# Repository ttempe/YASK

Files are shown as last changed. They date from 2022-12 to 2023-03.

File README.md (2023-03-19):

YASK - Yet Another Steno Keyboard.
This is a keyboard designed for use with Plover, through the Gemini PR protocol.

To order the PCB, send Gerber_PCB_Steno Keyboard.ZIP to your local PCB shop. Choose the default/cheapest answer to all their questions. 
Here are the build instructions for V1: https://youtu.be/82yD0RMeEw8
V2 instructions are upcoming.

You now have 2 versions to choose from:
* V1: is ortholinear, and uses Cherry-type key switches
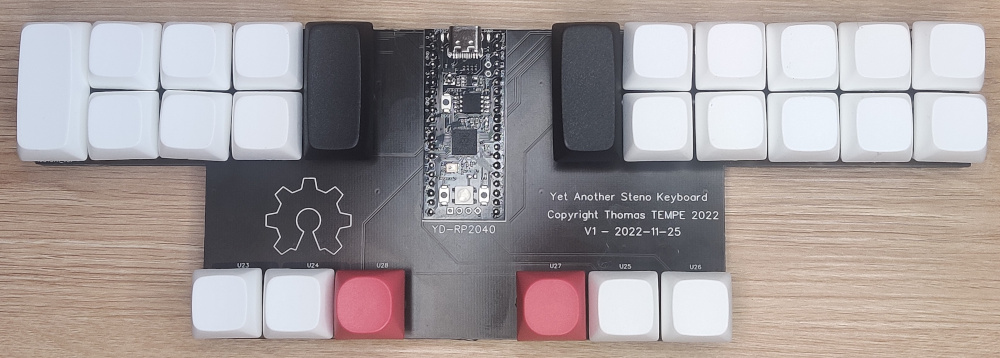
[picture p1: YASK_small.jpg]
Photo of YASK V1


* V2.1: has vertical stargger, is angled (10° each hand), requires Kailh Choc key switches (either with or without hot-swap sockets), and features optional key plates. Moreover the left pinky and the left/right # and * are wired separately, allowing for future evolutions.
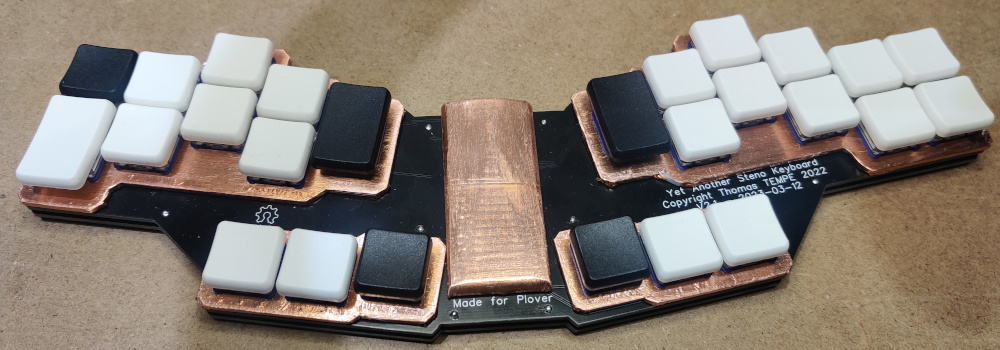
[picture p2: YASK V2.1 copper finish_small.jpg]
Photo of YASK V2 with custom copper finish


Here you can find the design files for the PCB: 
* YASK V1 on OSW Hub: https://oshwhub.com/thomastempe/steno-keyboard
* YASK V2 on OSW Hub: https://pro.lceda.cn/editor#id=24756c8465f9488d9ce5336baf65117a

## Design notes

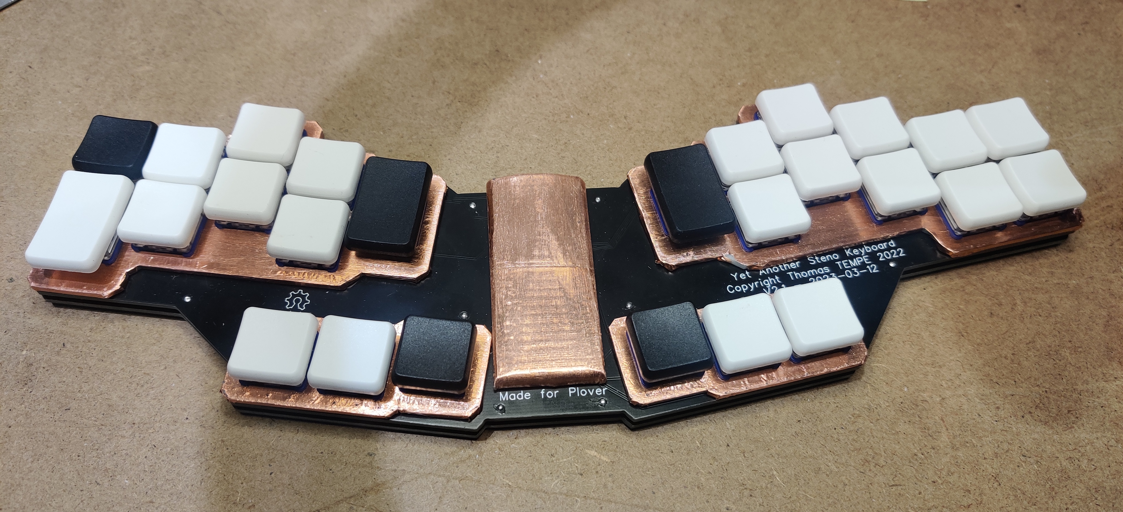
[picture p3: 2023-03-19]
YASK V2.1 copper finish.jpg

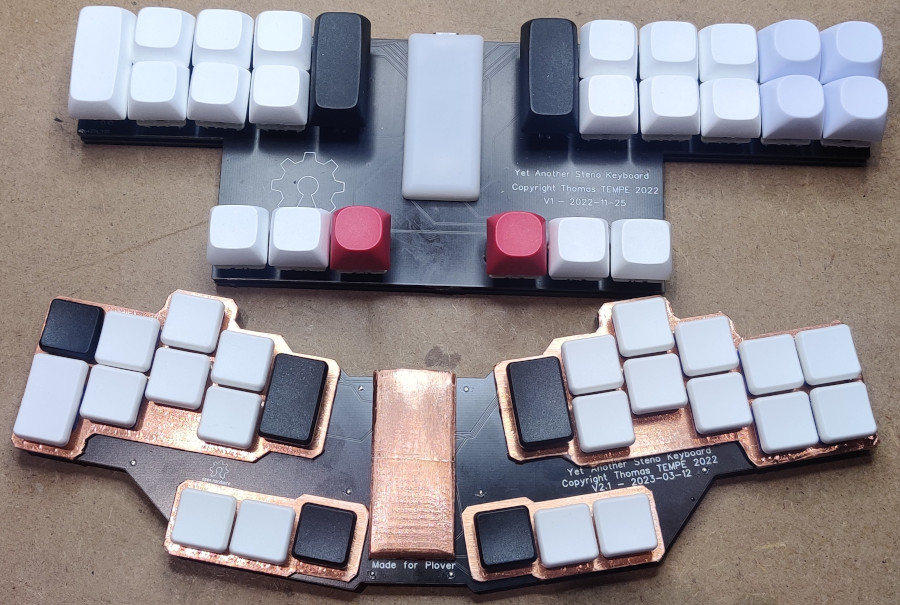
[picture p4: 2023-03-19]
YASK_V1_V2_small.jpg

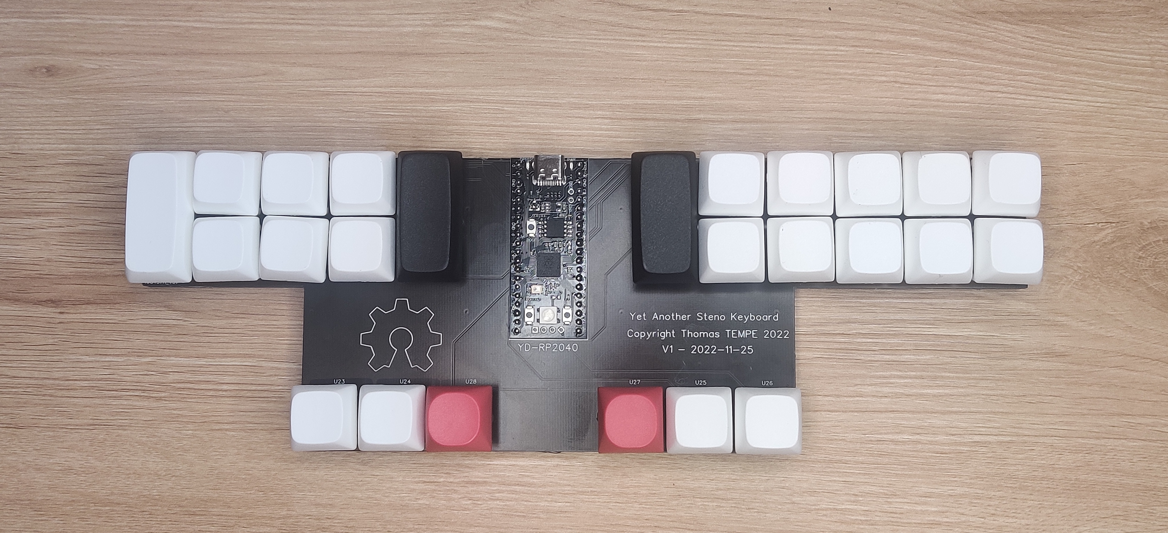
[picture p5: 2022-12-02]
YASK.jpg

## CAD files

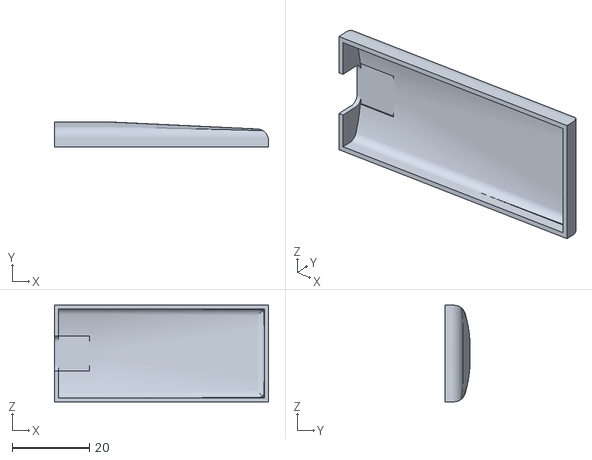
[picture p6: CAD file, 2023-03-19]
YAST V2.1 uc cover.stl
55.4 x 6.60 x 25.0

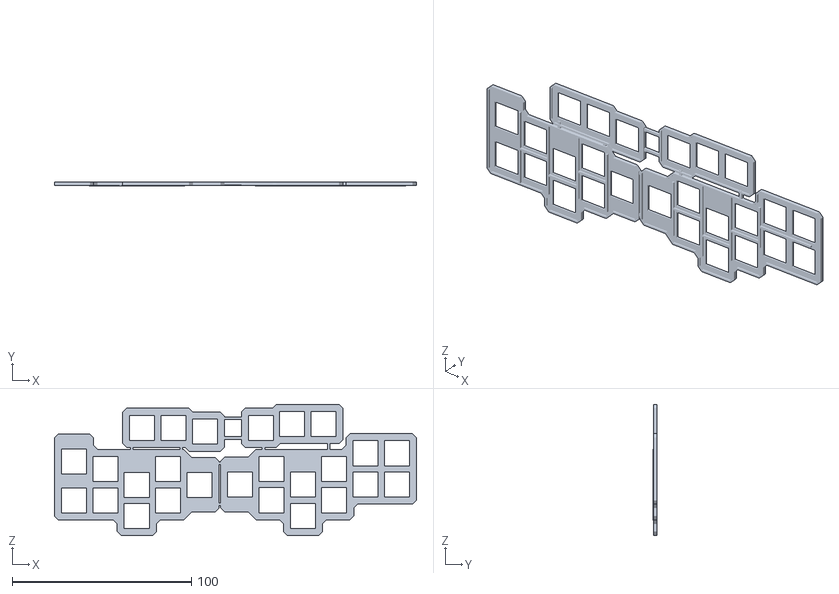
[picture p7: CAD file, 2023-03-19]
YASK V2.1 plates.stl
202.2 x 2.00 x 73.4

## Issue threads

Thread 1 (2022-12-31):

Bill of Materials (BoM) and Sources

zenny, 2022-12-31:
@ttempe

Thanks for posting this.

However, I wish you post a table of bill of materials (BoM) and the sources from where it can be ordered.

Some suggestions:
1. Btw, would it be not wonderful if you change the lower plate to a metal one or HDPE with a 3/4" knob at the center (similar to ectosteno or multisteno) to mount to a keyboard?
2. Can the board be a bit modded to look angled like BBSteno (https://mechwild.com/product/bb-steno/) for ergonomics?

Cheers and happy new year 2023.
/z

ttempe, 2024-03-03:
You are right, you can choose a mix of materials. My PCB manufacturer usually has a MOQ of 5, so unless you wanted to make more than 2 keyboards, a 2nd PCB makes the whole keyboard much more sturdy for basically free.

Regarding the BOM, please refer to the my comment on the Youtube video for V1. I can't recommend any suppliers, as I live in PR China and do my shopping on Taobao, which is not directly accessible outside China.

V2 is more aggressively angled than BBSteno it seems. The BOM is the same, except for the keys.

Have fun,

Closed 2024-03-03.

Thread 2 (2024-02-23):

hard to find kailh choc switches. alternatives?

jappyjan, 2024-02-23:
Is it possible to use different kind of switches?
It seems to be really hard to buy kailh choc switches currently...

ttempe, 2024-03-03:
Sorry, the Kailh Choc use a proprietary footprint, so if you want to used different switches on the YASK V2, you'll need to modify the PCB.

The V1 uses standard Cherry-type switch sockets, so no problem there. The software will work with any brand of switch as well.

Closed 2024-03-03.

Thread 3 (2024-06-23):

STL files of the v2 plates?

tocklime, 2024-06-23:
Would it be possible to get STL files of the v2 board support plates?

Thanks for your work on this - it looks amazing.

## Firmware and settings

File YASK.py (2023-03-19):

#Copyright Thomas TEMPE, 2022, DWTFYL license
#Works with MicroPython
import sys, time
from machine import Pin

#Config:
Plover_HID = False
Gemini_PR  = True
NKRO       = False

#YASK hardware version. Set to either 1 (for the ortholinear one) or 2 (for the contoured one)
version = 2

#These are not relevant on Plover-HID
FirstUpChordSend = True
AutoRepeat = False

### Extract from Plover code:
# In the Gemini PR protocol, each packet consists of exactly six bytes
# and the most significant bit (MSB) of every byte is used exclusively
# to indicate whether that byte is the first byte of the packet
# (MSB=1) or one of the remaining five bytes of the packet (MSB=0). As
# such, there are really only seven bits of steno data in each packet
# byte. This is why the STENO_KEY_CHART below is visually presented as
# six rows of seven elements instead of six rows of eight elements.

# STENO_KEY_CHART = ("Fn", "#1", "#2", "#3", "#4", "#5", "#6",
#                    "S1-", "S2-", "T-", "K-", "P-", "W-", "H-",
#                    "R-", "A-", "O-", "*1", "*2", "res1", "res2",
#                    "pwr", "*3", "*4", "-E", "-U", "-F", "-R",
#                    "-P", "-B", "-L", "-G", "-T", "-S", "-D",
#                    "#7", "#8", "#9", "#A", "#B", "#C", "-Z")
# 
#      #1 #2  #3 #4 #5 #6 #7 #8 #9 #A #B #C
#      Fn S1- T- P- H- *1 *3 -F -P -L -T -D
#         S2- K- W- R- *2 *4 -R -B -G -S -Z
#               A- O-       -E -U

#__keymap = {"N/A":22, "S-":0, "T-":1, "K-":2, "P-":3, "W-":4, "H-":5, "R-":6, "A":7, "O":8, "*":9, "Num":10, "E":11, "U":12, "-F":18, "-R":19, "-P":20, "-B":21, "-L":22, "-G":26, "-T":27, "-S":28, "-D":29, "-Z":23}
#__protocole = [["N/A", "Num", "Num", "Num", "Num", "Num", "Num",],
#               ["S-", "S-", "T-", "K-", "P-", "W-", "H-"],
#               ["R-",  "A", "O-", "*", "*", "N/A", "N/A"],
#               ["N/A", "*", "*",  "E", "U", "-F", "-R"],
#               ["-P", "-B", "-L", "-G", "-T", "-S", "-D"],
#               ["Num", "Num", "Num", "Num", "Num", "Num", "-Z"]]


#List of GPIOs connected to chording keys
if version == 1:
    __inputs =     [0, 1,  2, 3, 4, 5, 6, 7, 8, 9, 10, 11, 12, 18, 19, 20, 21, 22, 26, 27, 28, 15, 14, 16] #GPIO address
    #Corresponds to:S- T-  K- P- W- H- R- A  O  *  #    E   U  -F  -R  -P  -B  -L  -G  -T  -S  -D  -Z, N/A #key name
    #Index          0  1   2  3  4  5  6  7  8  9  10  11  12  13  14  15  16  17  18  19  20  21  22  23  #list index
    __equiv = [] #List of pairs of keys that are wired to different pins but need to be treated as equivalent. Must be indexes, not pin numbers.
elif version == 2:
    __inputs =     [0, 1,  2, 3, 4, 5, 6, 7, 8, 9, 10, 11, 12, 18, 19, 20, 21, 22, 26, 27, 28, 15, 14, 17, 13, 16] #GPIO address
    #Corresponds to:S- T-  K- P- W- H- R- A  O  *  #    E   U  -F  -R  -P  -B  -L  -G  -T  -S  -D  -Z, Esc, #  N/A #key name
    #Index          0  1   2  3  4  5  6  7  8  9  10  11  12  13  14  15  16  17  18  19  20  21  22  23  24  25  #list index
    __equiv = [(10,24), (9, 25), (23,0)] #List of pairs of keys that are wired to different pins but need to be treated as equivalent. Must be indexes, not pin numbers.

#Here is the index (in __inputs) of the GPIO used for each of the bits of 6 bytes of one protocole frame
__protocole = [[ 23, 10, 10, 10, 10, 10, 10],
               [  0,  0,  1,  2,  3,  4,  5],
               [  6,  7,  8,  9,  9, 23, 23],
               [ 23,  9,  9, 11, 12, 13, 14],
               [ 15, 16, 17, 18, 19, 20, 21],
               [ 10, 10, 10, 10, 10, 10, 22]]

#Bitmaps
#                ~ZDSTGLBPRFUE#*OARHWPKTS
__left_hand  = 0b000000000000000111111111
__right_hand = 0b011111111111100000000000

# Autorepeat configuration: 
#                      key states                  mask: which keys to match?
#                        ZDSTGLBPRFUE#*OARHWPKTS    ZDSTGLBPRFUE#*OARHWPKTS
__autoRepeatRules = [ (0b00000000000000001010101, 0b11110000001111111111111),  #Ted's navigation: move cursor
                      (0b00000000000000001010101, 0b11110000001111111111111),  #Ted's navigation: move cursor
                      (0b00000000000000000101011, 0b11110000001111111111111),  #Ted's navigation: select
                    ]
__autoRepeatDelay = 700 #before 1st repeat
__autoRepeatRepeat= 300 #between subsequent repeats

__LED = Pin(25, Pin.OUT)

def equiv(bitmap, id1, id2):
    "set to 'pressed' the signal of both key ids if either one is pressed"
    v = ((bitmap>>id1)&1) | ((bitmap>>id2)&1)
    return bitmap | (v<<id1) | (v<<id2)
    

class YASK:    
    def __init__(self):
        self.keymap = {}
        self.inputs_max = 0 #Bitmap (order is same as __inputs) 
        self.buffer = bytearray(6)
        self.keys = [] #List of Pin objects corresponding to __inputs
        for i in __inputs:
            self.keys.append(Pin(i, Pin.IN, Pin.PULL_UP)) 
        #print("Yet Another Chording Keyboard\nCopyright Thomas TEMPE 2022")
        
    def Gemini_write(self):
        #Write stroke to USB
        if Gemini_PR:
            for c in range(6):
                self.buffer[c] = 0
                for i, j in enumerate(__protocole[c]):
                    self.buffer[c] += ((self.inputs_max>>__protocole[c][i])&0x01)<<(6-i)
            self.buffer[0] += 0x80
            sys.stdout.buffer.write(self.buffer)

    def test_keys(self):
        inputs = 0
        while True:
            inputs_old = inputs
            inputs = 0
            for i, v in enumerate(self.keys):
                vv=v()
                inputs += (vv^1) << i
                if ((inputs_old>>i) & 1) != (vv^1):
                    print(v, [" pressed", "released"][vv])
            time.sleep_ms(100)

                
            

    def loop(self):
        left, right, left_max, right_max = (0, 0, 0, 0) #bitmaps, like self.input_max
        already_written = False
        timeStamp = 0
        inputs = 0
        t0 = 0
        repeatingStarted = False
        autoRepeatEngaged = False
       
        while True:
            #polls in a loop
            inputs_old = inputs
            inputs = 0
            for i, v in enumerate(self.keys):
                inputs += (v()^1) << i
            for e in __equiv:
                inputs = equiv(inputs, *e)
            self.inputs_max = inputs | self.inputs_max
            left  = inputs & __left_hand
            right = inputs & __right_hand
            left_max  = left  | left_max
            right_max = right | right_max
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

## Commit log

2022-12-14 Flash LED when sending a stroke
2023-01-29 V1.1: compatible with RP Pico and RP Pico W
    Move some pins to make it compatible with Raspberry Pi official boards.
    Please consder supporting the Raspberry Pi foundation by buying official boards.
2023-01-31 HW version V1.1
    Change some pin assignments to make them compatible with Raspberry Pi RP Pico original boards.
2023-01-31 Adjust PCB outline to accomodate 2U thumb keys
2023-03-19 V2.1 done
    [YASK V2.1 plates.stl, YAST V2.1 uc cover.stl]
